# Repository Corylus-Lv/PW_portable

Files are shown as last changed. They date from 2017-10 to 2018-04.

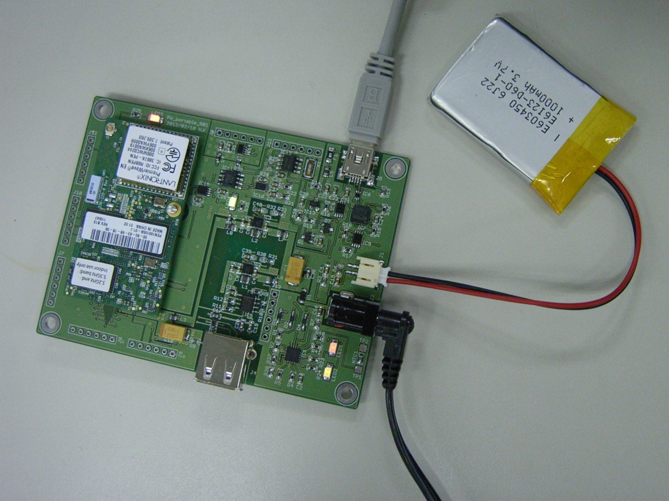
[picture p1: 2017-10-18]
photo1.jpg

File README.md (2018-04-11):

# PremierWave-EN Portable Board

過去に作った基板のEAGLE設計データを公開します。
LANTRONIX社のPremierWave-ENを使った応用基板ですが、リチウムイオン・バッテリーを使った移動機器に応用できるかもしれません。

**特に注意すべき事項：**  
リチウムイオン・バッテリーを使っているので、バッテリー容量に見合った充電電流を設定しないと、バッテリの破裂・炎上などの大きな事故につながる可能性がありますので、十分注意してください（LTC4055のデータシートを熟読する）

CC BY-NC-SA 3.0

**免責事項：**  
このプロジェクトに掲載した情報については「現状のまま」で、明示であるか暗黙であるかを問わず、何らの保証もありません。 
この情報の利用またはその他の扱いに関連した、請求、損害、その他の義務については一切の責任を負うものではありません。

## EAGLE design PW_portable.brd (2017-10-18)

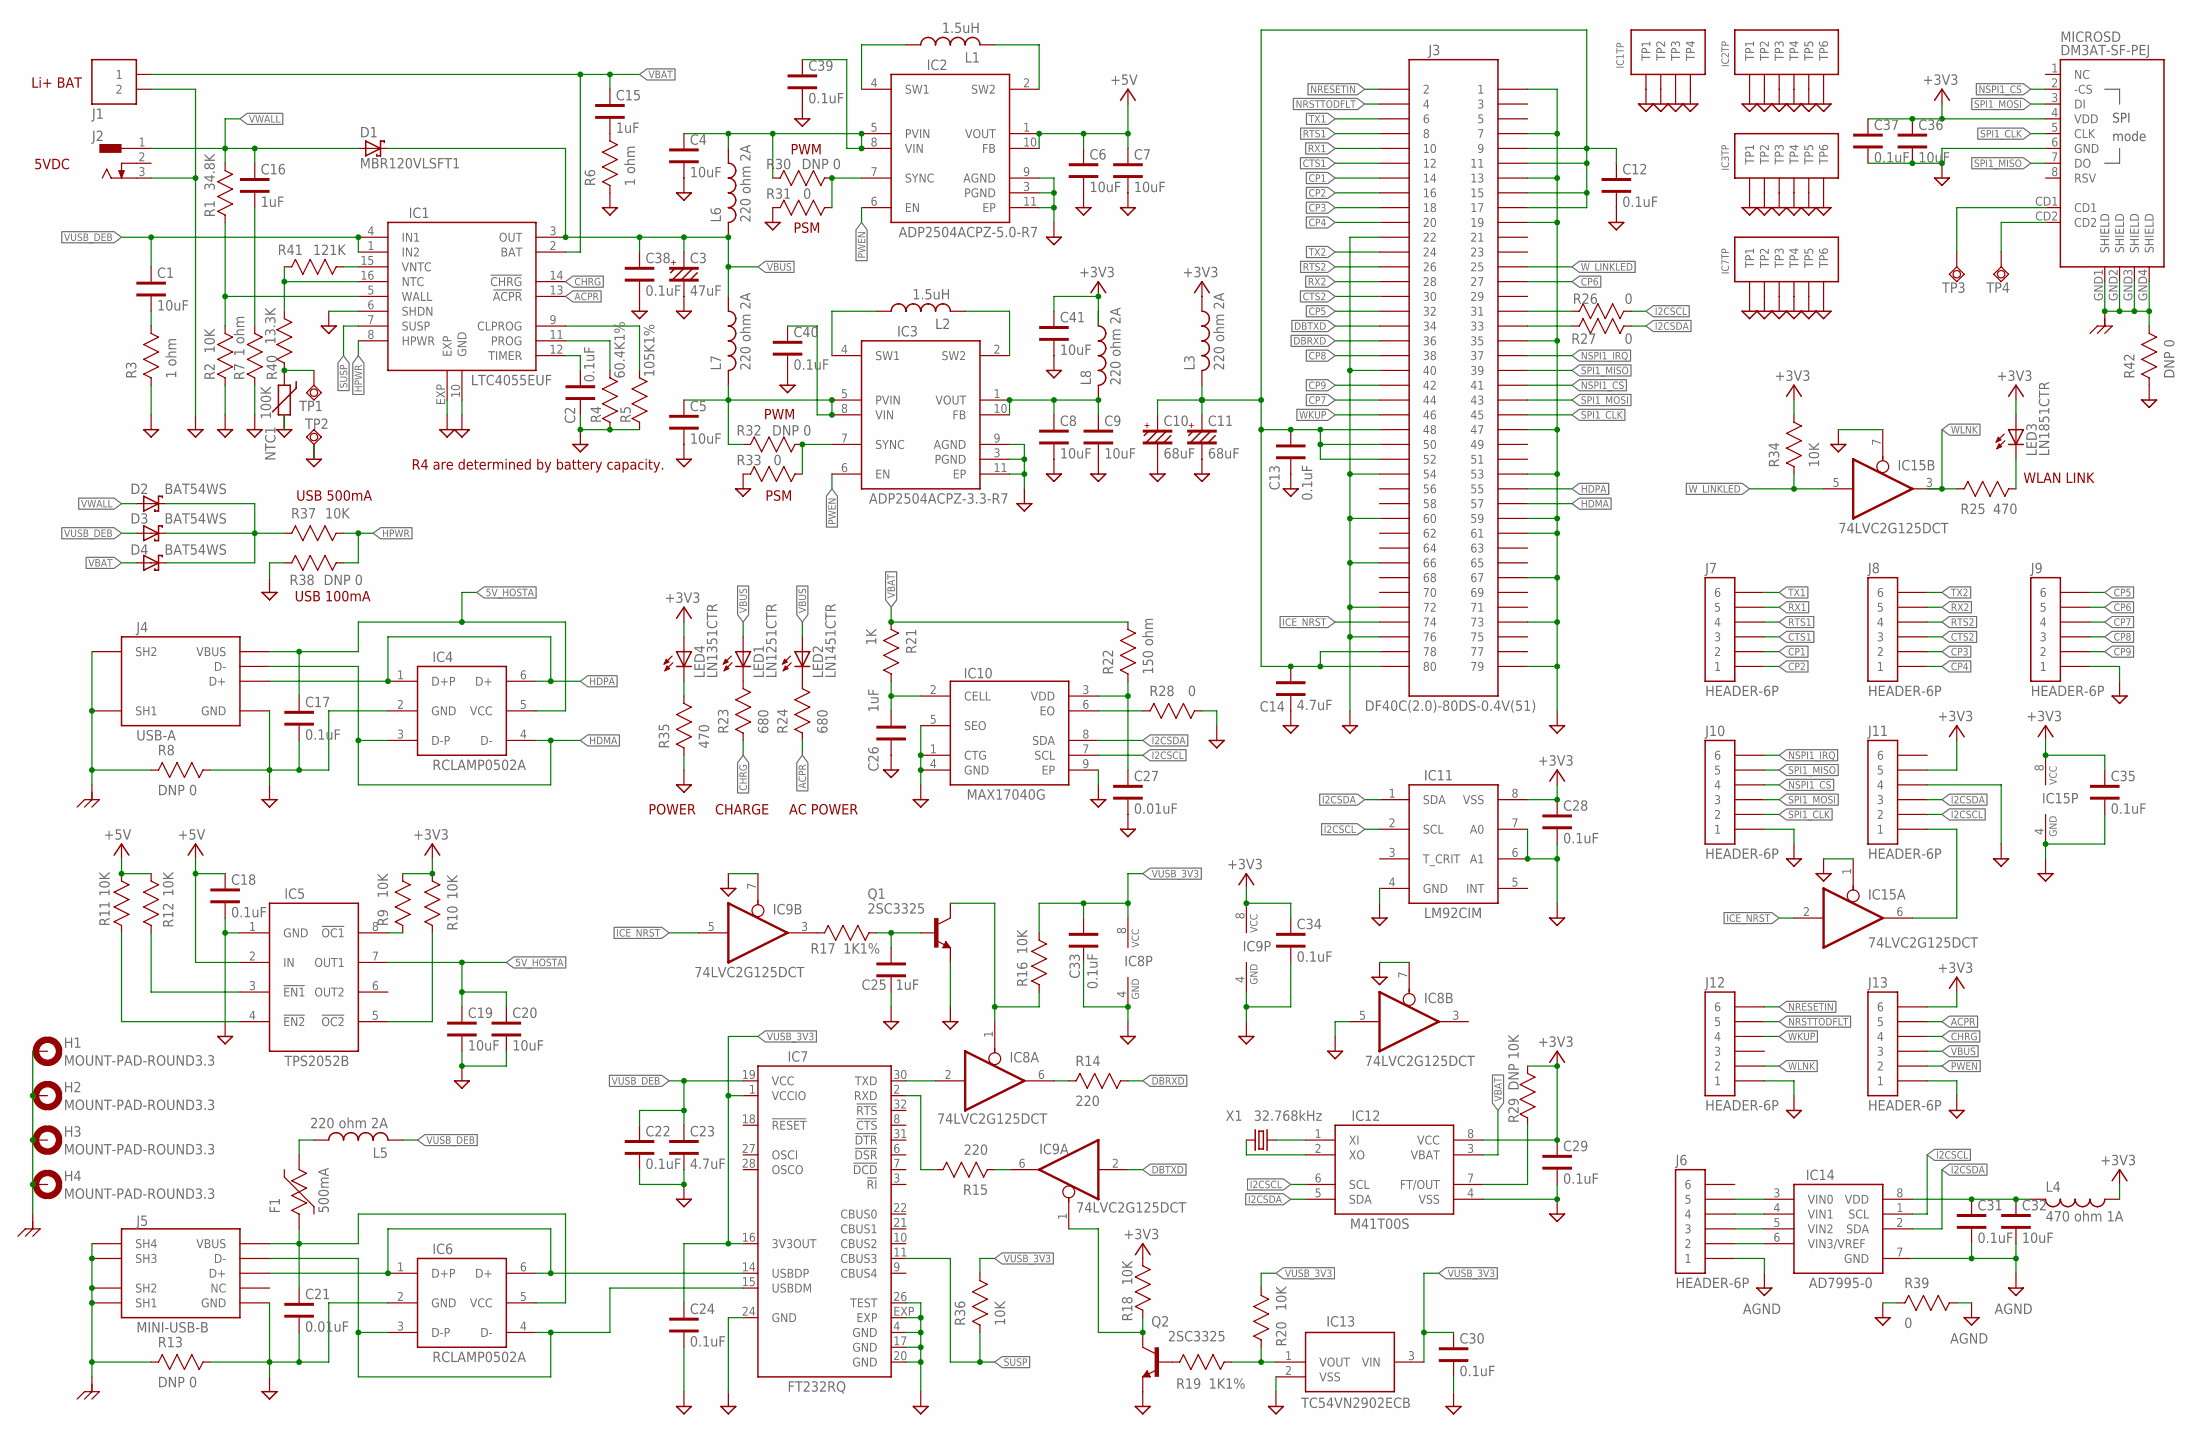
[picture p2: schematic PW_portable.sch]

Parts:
C1, C4, C5, C6, C7, C8, C9, C19, C20, C32, C36, C41: 10uF; C0603
C2, C12, C13, C17, C18, C22, C24, C28, C29, C30, C31, C33, C34, C35, C37, C38, C39, C40: 0.1uF; C0603
C3: 47uF; SMC_D
C10, C11: 68uF; SMC_D
C14, C23: 4.7uF; C0603
C15, C16, C25, C26: 1uF; C0603
C21, C27: 0.01uF; C0603
D1: MBR120VLSFT1; SOD123FL
D2, D3, D4: BAT54WS; SOD323
F1: 500mA; P1206
H1, H2, H3, H4: MOUNT-PAD-ROUND3.3; 3,3-PAD
IC1: LTC4055EUF; QFN16-4X4
IC2: ADP2504ACPZ-5.0-R7; LFCSP_WD-CP-10-9
IC3: ADP2504ACPZ-3.3-R7; LFCSP_WD-CP-10-9
IC4, IC6: RCLAMP0502A; SOT666
IC5: TPS2052B; D_R-PDSO-G08
IC7: FT232RQ; QFN32
IC8, IC9, IC15: 74LVC2G125DCT; SSOP08
IC10: MAX17040G; 8-TDFN
IC11: LM92CIM; SO08
IC12: M41T00S; SO08
IC13: TC54VN2902ECB; SOT23
IC14: AD7995-0; SOT23-8
J1: JACK-JST-2P-PW'SMD'; JST-SMD-2.0
J2: DCJ0202
J3: DF40C(2.0)-80DS-0.4V(51)
J4: USB-A
J5: MINI-USB-B; 1734035-2
J6, J7, J8, J9, J10, J11, J12, J13: HEADER-6P; 6P-2.54
L1, L2: 1.5uH; L1008
L3, L5, L6, L7, L8: 220 ohm 2A; L0603
L4: 470 ohm 1A; L0603
LED1: LN1251CTR; LED1208
LED2: LN1451CTR; LED1208
LED3: LN1851CTR; LED1208
LED4: LN1351CTR; LED1208
MICROSD: DM3AT-SF-PEJ
NTC1: 100K; R0603
Q1, Q2: 2SC3325; SOT23-BEC
R1: 34.8K; R0603
R2, R9, R10, R11, R12, R16, R18, R20, R34, R36, R37: 10K; R0603
R3, R6, R7: 1 ohm; R0603
R4: 60.4K1%; R0603
R5: 105K1%; R0603
R8, R13, R30, R32, R38, R42: DNP 0; R0603
R14, R15: 220; R0603
R17, R19: 1K1%; R0603
R21: 1K; R0603
R22: 150 ohm; R0603
R23, R24: 680; R0603
R25, R35: 470; R0603
R26, R27, R28, R31, R33, R39: 0; R0603
R29: DNP 10K; R0603
R40: 13.3K; R0603
R41: 121K; R0603
TP1, TP2, TP3, TP4: TPSQTP20SQ; TP20SQ
X1: 32.768kHz; FC255

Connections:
5V_HOSTA: C17.1, C19.1, C20.1, IC4.5 (VCC), IC5.7 (OUT1), J4.1 (VBUS)
+3V3: C28.1, C29.1, C34.1, C35.1, C36.1, C37.1, C41.1, IC9.8 (VCC), IC11.8 (VSS), IC12.8 (VCC), IC15.8 (VCC), J11.5, J13.6, L3.1, L4.1, L8.1, LED3.A, LED4.A, MICROSD.4 (VDD), R9.2, R10.2, R18.1, R29.2, R34.2
+5V: C6.1, C7.1, C18.1, IC2.1 (VOUT), IC2.10 (FB), IC5.2 (IN), R11.2, R12.2
ACPR: IC1.13 (!ACPR), J13.5, R24.1
AGND: C31.2, C32.2, IC14.7 (GND), J6.1, R39.2
CHRG: IC1.14 (!CHRG), J13.4, R23.1
CP1: J3.14, J7.2
CP2: J3.16, J7.1
CP3: J3.18, J8.2
CP4: J3.20, J8.1
CP5: J3.32, J9.6
CP6: J3.27, J9.5
CP7: J3.44, J9.4
CP8: J3.38, J9.3
CP9: J3.42, J9.2
CTS1: J3.12, J7.3
CTS2: J3.30, J8.3
DBRXD: J3.36, R14.2
DBTXD: IC9.2 (I), J3.34
DGND: C2.2, C3.-, C4.2, C5.2, C6.2, C7.2, C8.2, C9.2, C10.-, C11.-, C12.2, C13.2, C14.2, C17.2, C18.2, C19.2, C20.2, C21.2, C22.2, C23.2, C24.2, C25.2, C26.2, C27.2, C28.2, C29.2, C30.2, C33.2, C34.2, C35.2, C36.2, C37.2, C38.2, C39.2, C40.2, C41.2, IC1.6 (SHDN), IC1.10 (GND), IC1.EXP, IC1.P$1 (TP1), IC1.P$2 (TP2), IC1.P$3 (TP3), IC1.P$4 (TP4), IC2.3 (PGND), IC2.9 (AGND), IC2.11 (EP), IC2.P$1 (TP1), IC2.P$2 (TP2), IC2.P$3 (TP3), IC2.P$4 (TP4), IC2.P$5 (TP5), IC2.P$6 (TP6), IC3.3 (PGND), IC3.9 (AGND), IC3.11 (EP), IC3.P$1 (TP1), IC3.P$2 (TP2), IC3.P$3 (TP3), IC3.P$4 (TP4), IC3.P$5 (TP5), IC3.P$6 (TP6), IC4.2 (GND), IC5.1 (GND), IC6.2 (GND), IC7.4 (GND), IC7.17 (GND), IC7.20 (GND), IC7.24 (GND), IC7.26 (TEST), IC7.EXP, IC7.P$1 (TP1), IC7.P$2 (TP2), IC7.P$3 (TP3), IC7.P$4 (TP4), IC7.P$5 (TP5), IC7.P$6 (TP6), IC8.4 (GND), IC8.5 (I), IC8.7 (OE), IC9.4 (GND), IC9.7 (OE), IC10.1 (CTG), IC10.4 (GND), IC10.5 (SEO), IC10.9 (EP), IC11.4 (GND), IC11.6 (A1), IC11.7 (A0), IC12.4 (VSS), IC13.2 (VSS), IC15.1 (OE), IC15.4 (GND), IC15.7 (OE), J1.2, J2.3, J3.1, J3.7, J3.13, J3.19, J3.22, J3.35, J3.40, J3.47, J3.53, J3.54, J3.59, J3.60, J3.61, J3.66, J3.67, J3.72, J3.73, J3.76, J3.79, J4.4 (GND), J5.5 (GND), J9.1, J10.1, J11.4, J12.1, J13.1, MICROSD.6 (GND), NTC1.2, Q1.E, Q2.E, R2.1, R3.1, R4.1, R5.1, R6.1, R7.1, R8.2, R13.2, R28.2, R31.1, R33.1, R35.1, R38.1, R39.1, R42.1, TP2.TP
EGND: H1.B3,3, H2.B3,3, H3.B3,3, H4.B3,3, J4.5 (SH1), J4.6 (SH2), J5.M1 (SH1), J5.M2 (SH2), J5.M3 (SH3), J5.M4 (SH4), MICROSD.GND1 (SHIELD), MICROSD.GND2 (SHIELD), MICROSD.GND3 (SHIELD), MICROSD.GND4 (SHIELD), R8.1, R13.1, R42.2
HDMA: IC4.3 (D-P), IC4.4 (D-), J3.57, J4.2 (D-)
HDPA: IC4.1 (D+P), IC4.6 (D+), J3.55, J4.3 (D+)
HPWR: IC1.8 (HPWR), R37.2, R38.2
I2CSCL: IC10.7 (SCL), IC11.2 (SCL), IC12.6 (SCL), IC14.1 (SCL), J11.2, R26.2
I2CSDA: IC10.8 (SDA), IC11.1 (SDA), IC12.5 (SDA), IC14.2 (SDA), J11.3, R27.2
ICE_NRST: IC9.5 (I), IC15.2 (I), J3.74
unnamed: NTC1.1, R40.1, TP1.TP
unnamed: C26.1, IC10.2 (CELL), R21.2
unnamed: C2.1, IC1.12 (TIMER)
unnamed: C27.1, IC10.3 (VDD), R22.1
unnamed: IC1.5 (WALL), R1.1, R2.2
unnamed: C1.2, R3.2
unnamed: IC1.11 (PROG), R4.2
unnamed: IC1.9 (CLPROG), R5.2
unnamed: IC2.4 (SW1), L1.1
unnamed: IC2.2 (SW2), L1.2
unnamed: IC3.4 (SW1), L2.1
unnamed: IC3.2 (SW2), L2.2
unnamed: C10.+, C11.+, C12.1, C13.1, C14.1, J3.9, J3.11, J3.15, J3.17, J3.48, J3.50, J3.52, J3.78, J3.80, L3.2
unnamed: C16.2, R7.2
unnamed: IC5.3 (!EN1), R12.1
unnamed: IC5.8 (!OC1), R9.1
unnamed: IC5.5 (!OC2), R10.1
unnamed: C15.2, R6.2
unnamed: IC5.4 (!EN2), R11.1
unnamed: IC8.1 (OE), Q1.C, R16.1
unnamed: IC6.1 (D+P), IC6.6 (D+), IC7.14 (USBDP), J5.3 (D+)
unnamed: C21.1, F1.1, IC6.5 (VCC), J5.1 (VBUS)
unnamed: IC6.3 (D-P), IC6.4 (D-), IC7.15 (USBDM), J5.2 (D-)
unnamed: C25.1, Q1.B, R17.1
unnamed: IC9.1 (OE), Q2.C, R18.2
unnamed: Q2.B, R19.1
unnamed: IC7.30 (TXD), IC8.2 (I)
unnamed: IC7.2 (RXD), R15.2
unnamed: IC9.6 (O), R15.1
unnamed: IC8.6 (O), R14.1
unnamed: IC13.1 (VOUT), R19.2, R20.1
unnamed: IC10.6 (EO), R28.1
unnamed: IC9.3 (O), R17.2
unnamed: C31.1, C32.1, IC14.8 (VDD), L4.2
unnamed: IC12.2 (XO), X1.1
unnamed: LED1.C, R23.2
unnamed: LED2.C, R24.2
unnamed: IC14.6 (VIN3/VREF), J6.2
unnamed: IC14.5 (VIN2), J6.3
unnamed: IC14.4 (VIN1), J6.4
unnamed: IC14.3 (VIN0), J6.5
unnamed: IC15.6 (O), J11.1
unnamed: LED3.C, R25.2
unnamed: MICROSD.CD1, TP3.TP
unnamed: IC12.1 (XI), X1.2
unnamed: IC12.7 (FT/OUT), R29.1
unnamed: J3.31, R26.1
unnamed: J3.33, R27.1
unnamed: IC2.7 (SYNC), R30.2, R31.2
unnamed: IC3.7 (SYNC), R32.2, R33.2
unnamed: MICROSD.CD2, TP4.TP
unnamed: LED4.C, R35.2
unnamed: F1.2, L5.1
unnamed: C5.1, C40.1, IC3.5 (PVIN), IC3.8 (VIN), L7.2, R32.1
unnamed: C4.1, C39.1, IC2.5 (PVIN), IC2.8 (VIN), L6.1, R30.1
unnamed: D2.C, D3.C, D4.C, R37.1
unnamed: IC1.15 (VNTC), R41.1
unnamed: IC1.16 (NTC), R40.2, R41.2
unnamed: C8.1, C9.1, IC3.1 (VOUT), IC3.10 (FB), L8.2
NRESETIN: J3.2, J12.6
NRSTTODFLT: J3.4, J12.5
NSPI1_CS: J3.41, J10.4, MICROSD.2 (-CS)
NSPI1_IRQ: J3.37, J10.6
PWEN: IC2.6 (EN), IC3.6 (EN), J13.2
RTS1: J3.8, J7.4
RTS2: J3.26, J8.4
RX1: J3.10, J7.5
RX2: J3.28, J8.5
SPI1_CLK: J3.45, J10.2, MICROSD.5 (CLK)
SPI1_MISO: J3.39, J10.5, MICROSD.7 (DO)
SPI1_MOSI: J3.43, J10.3, MICROSD.3 (DI)
SUSP: IC1.7 (SUSP), IC7.11 (CBUS3), R36.1
TX1: J3.6, J7.6
TX2: J3.24, J8.6
VBAT: C15.1, D4.A, IC1.2 (BAT), IC12.3 (VBAT), J1.1, R21.1, R22.2
VBUS: C3.+, C38.1, D1.C, IC1.3 (OUT), J13.3, L6.2, L7.1, LED1.A, LED2.A
VUSB_3V3: C24.1, C30.1, C33.1, IC7.1 (VCCIO), IC7.16 (3V3OUT), IC8.8 (VCC), IC13.3 (VIN), R16.2, R20.2, R36.2
VUSB_DEB: C1.1, C22.1, C23.1, D3.A, IC1.1 (IN2), IC1.4 (IN1), IC7.19 (VCC), L5.2
VWALL: C16.1, D1.A, D2.A, J2.1, R1.2
WKUP: J3.46, J12.4
WLNK: IC15.3 (O), J12.2, R25.1
W_LINKLED: IC15.5 (I), J3.25, R34.1

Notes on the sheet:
Li+ BAT
5VDC
POWER
CHARGE
AC POWER
WLAN LINK
USB 500mA
USB 100mA
PWM
PSM
R4 are determined by battery capacity.

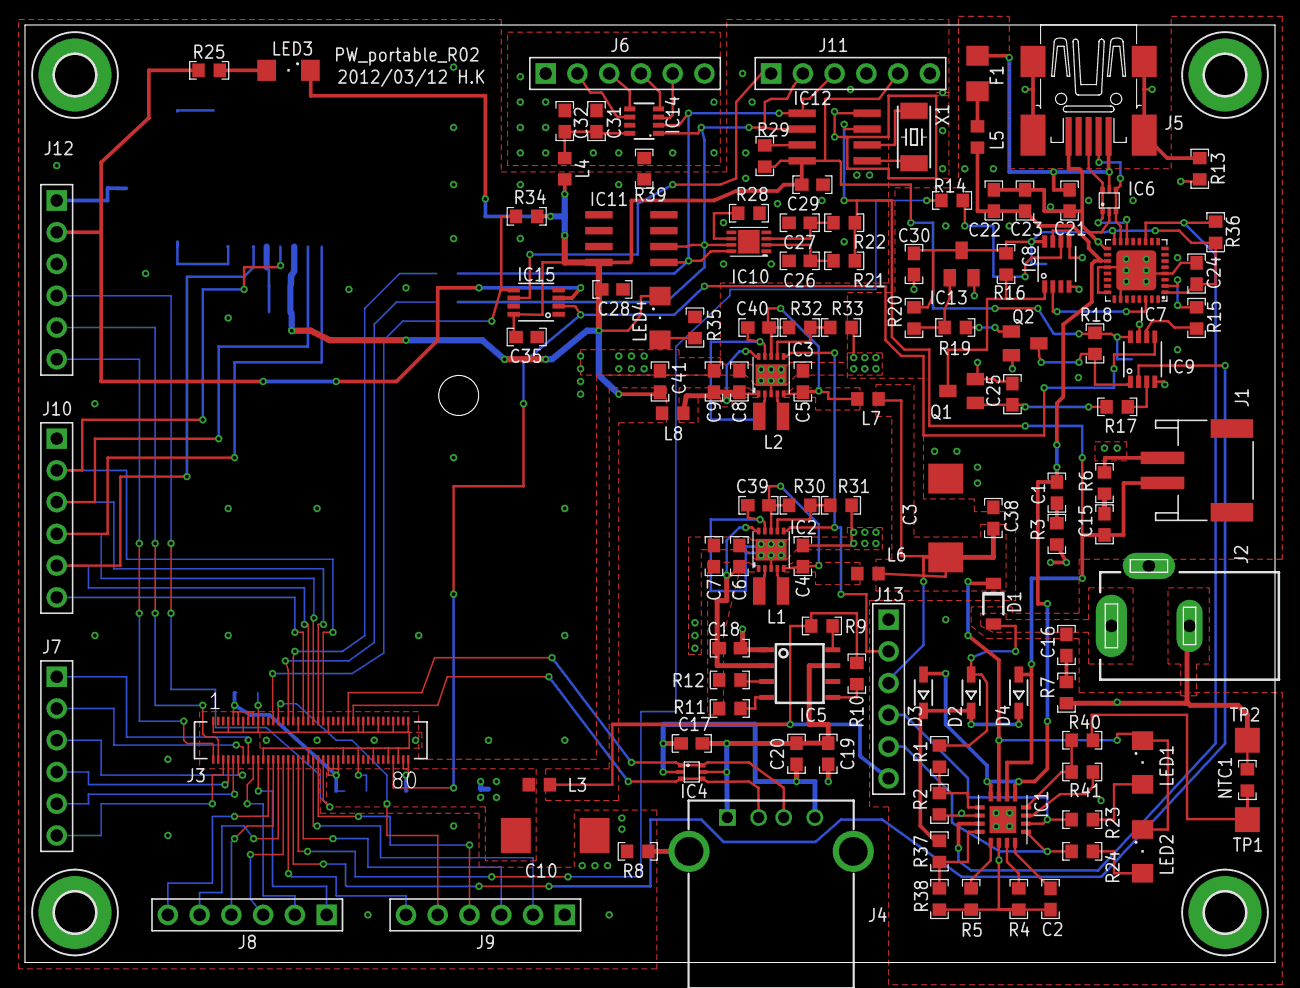
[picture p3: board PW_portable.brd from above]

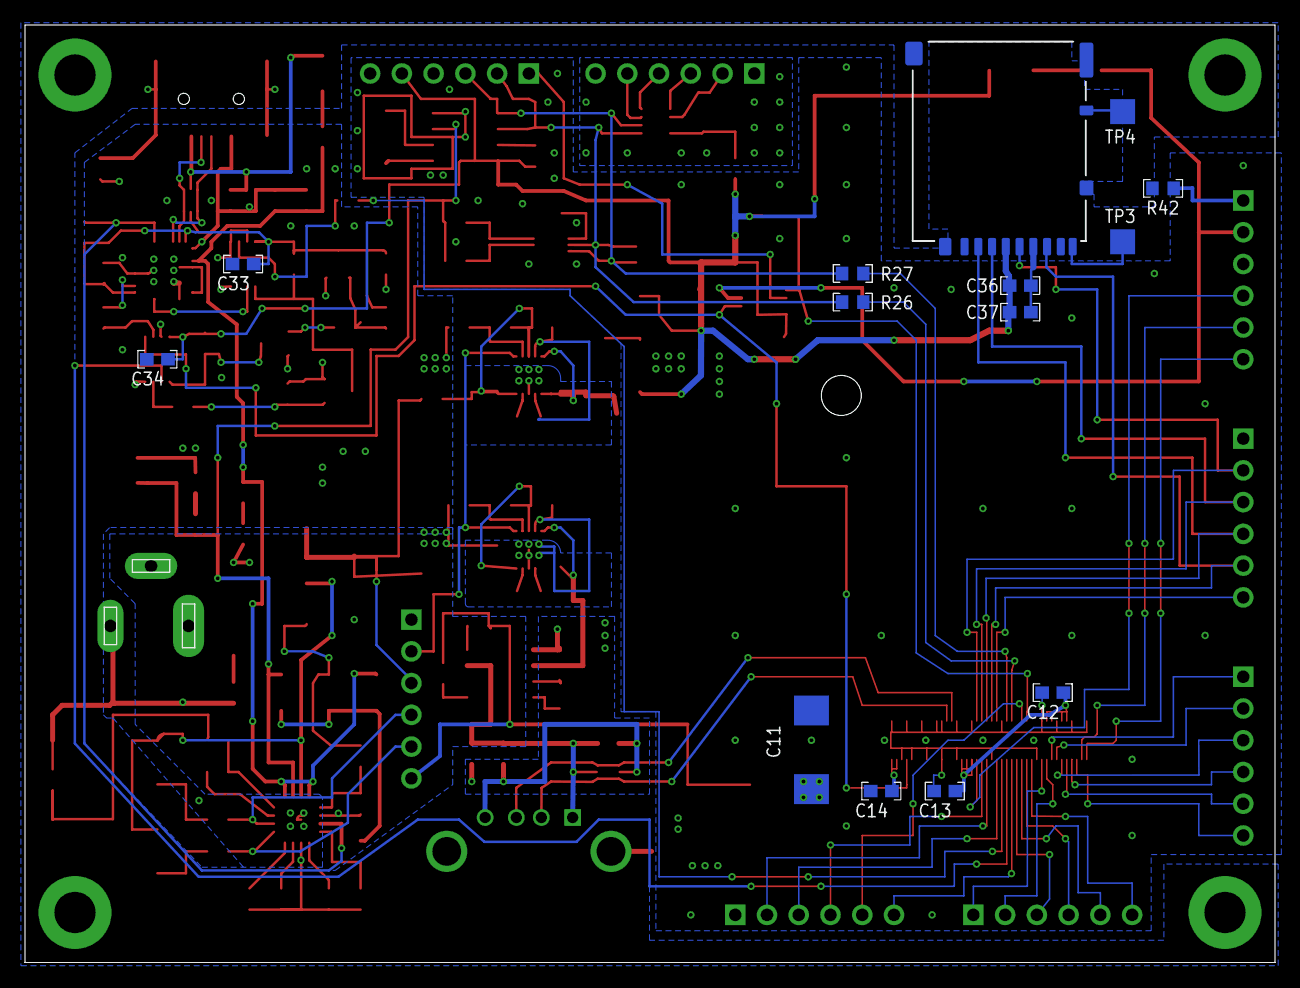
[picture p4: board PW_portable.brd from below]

Board: 2 copper layers, 100.0 x 75.0 mm, 141 parts (14 on the bottom side), 109 nets.
